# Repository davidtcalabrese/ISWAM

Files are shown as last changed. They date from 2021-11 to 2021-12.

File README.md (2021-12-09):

# ISWAM
## IoT Severe Weather Alert Monitor ⛈️ 🚨 🌪️ 🚨 🌊

ISWAM's purpose is to inform users in real time about current weather conditions as well as any possible alerts. It consists of a full stack node  application that accesses and processes NWS alerts and live weather data, and then broadcasts it to the browser  as well as on an IoT device I'm calling "The Puck". The Puck is an ESP32 microcontroller with integrated  WiFi attached to a small LCD screen and a ring of colorful LEDs. It's enclosed in a 3d-printed plastic case that resembles a hockey puck. 

The front end receives a zip code from the user, sends it to a node application for processing, receives the response and displays it to the page. The node application receives the parameters from the user, and consumes various REST APIs to collect data on current weather conditions as well as any potential safety alerts. It then processes and formats the data, sending the results back to the front end as well as to The Puck which exposes its own API.   
 
### APIs used
* [National Weather Service API ](https://www.weather.gov/documentation/services-web-api)
  * alert from UGC endpoint: /alerts/active/zone/{zoneId}
  * UGC from coordinates endpoint: https://api.weather.gov/points/{lat},{long}
  * Coordinates from UGC endpoint (for testing): https://api.weather.gov/zones/forecast/{UGC}
* [Weatherbit.io API](https://www.weatherbit.io/api)
  * weather from zipcode endpoint: https://api.weatherbit.io/v2.0/current/&postal_code={zip}&country=US
* [Zippopatmus](https://www.zippopotam.us/)
  * Geographic coordinates from zipcode endpoint: http://api.zippopotam.us/us/${zip} 
  * Alert from zip codehttps://api.weatherbit.io/v2.0/alerts?country=US&postal_code={zip}
* [Google Maps Geocoding API](https://developers.google.com/maps/documentation/geocoding/start)
  * Used the reverse geocoding API for testing purposes, zip code from coordinates: https://maps.googleapis.com/maps/api/geocode/json?latlng={lat},{long}

### Flowchart
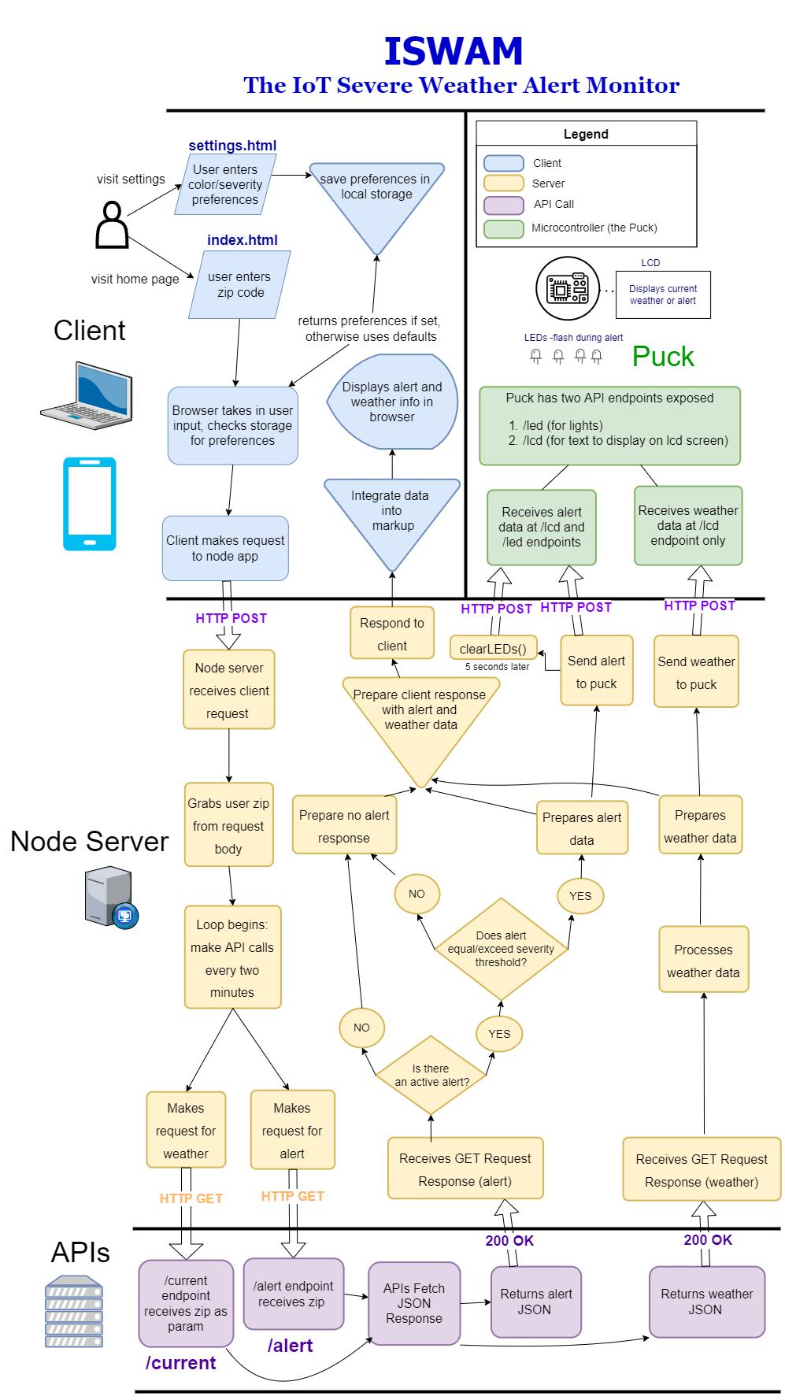
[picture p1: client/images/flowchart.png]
ISWAM Flowchart


### Images
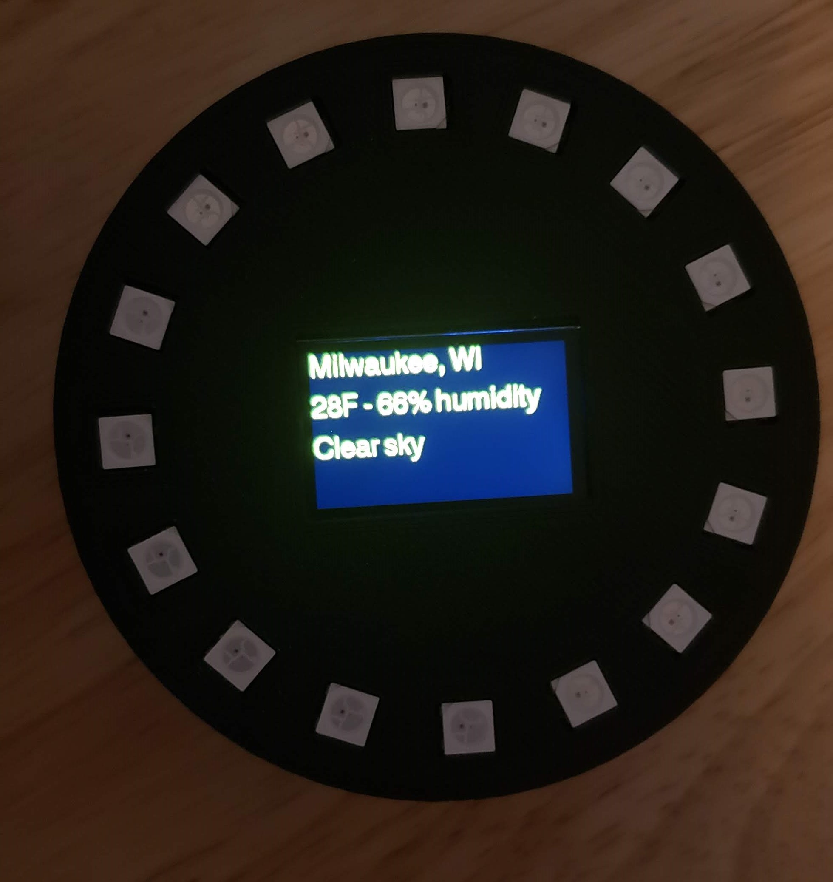
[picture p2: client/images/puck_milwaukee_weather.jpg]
Puck Weather Display

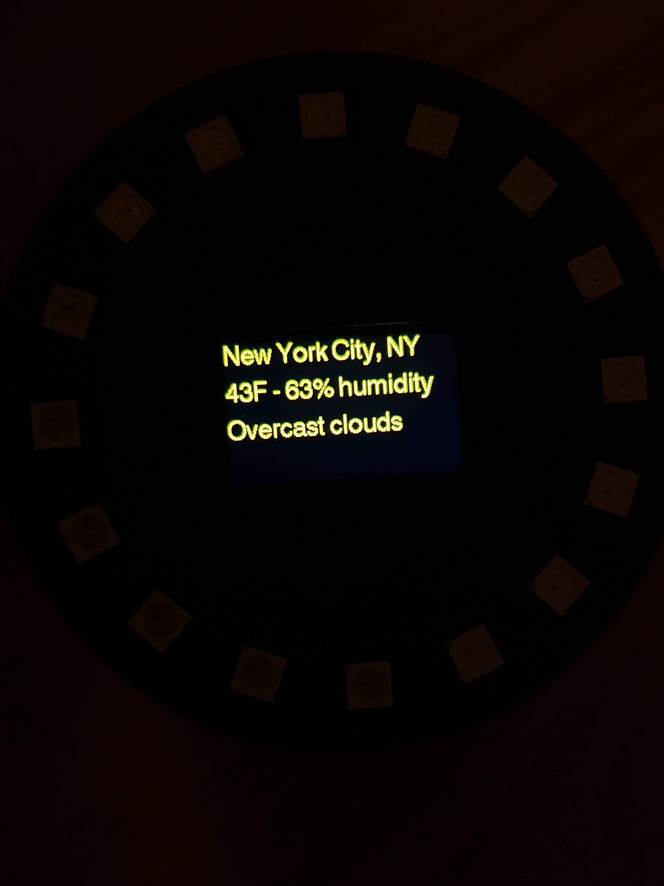
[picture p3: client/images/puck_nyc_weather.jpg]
Puck Weather Display

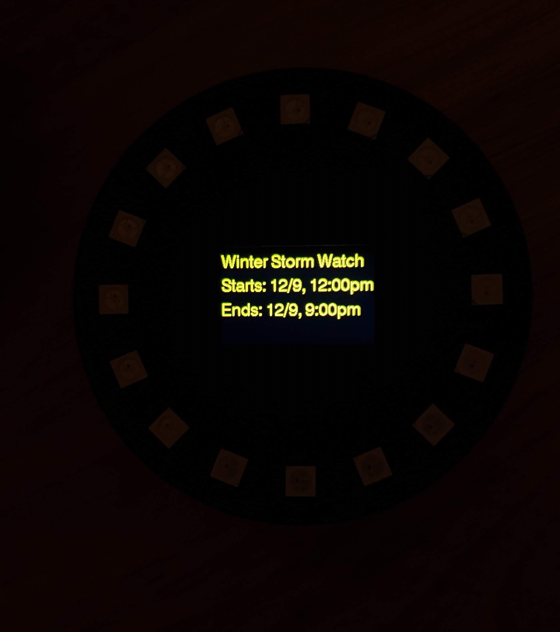
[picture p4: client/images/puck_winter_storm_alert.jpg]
Puck Alert Display

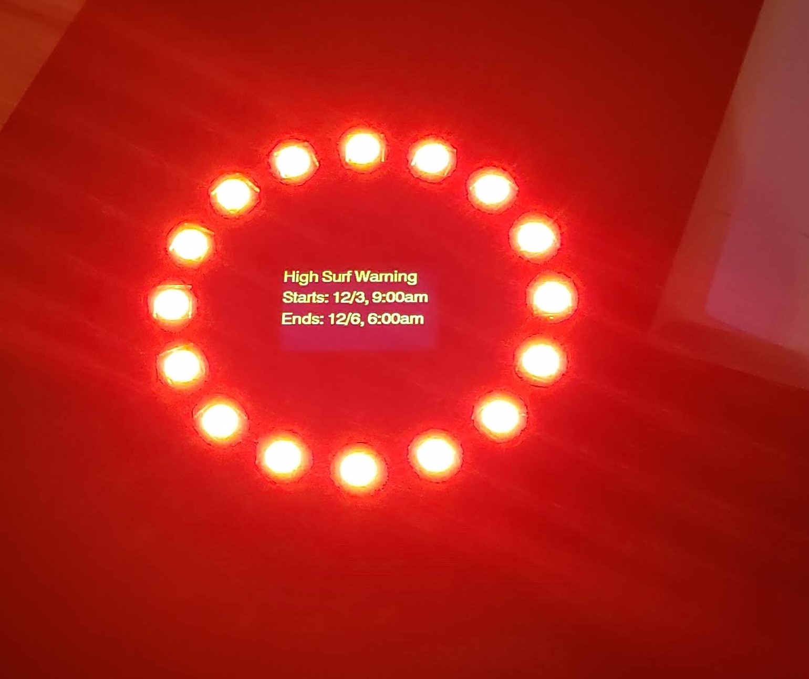
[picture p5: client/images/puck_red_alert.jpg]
Puck Alert Red

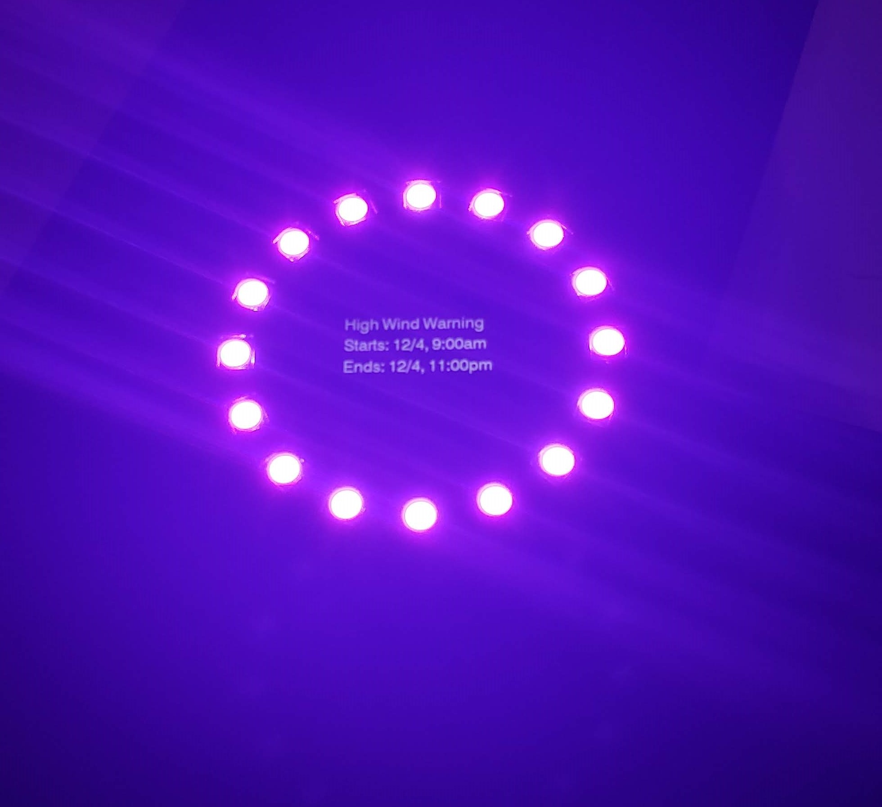
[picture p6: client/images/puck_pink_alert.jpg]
Puck Pink Pink

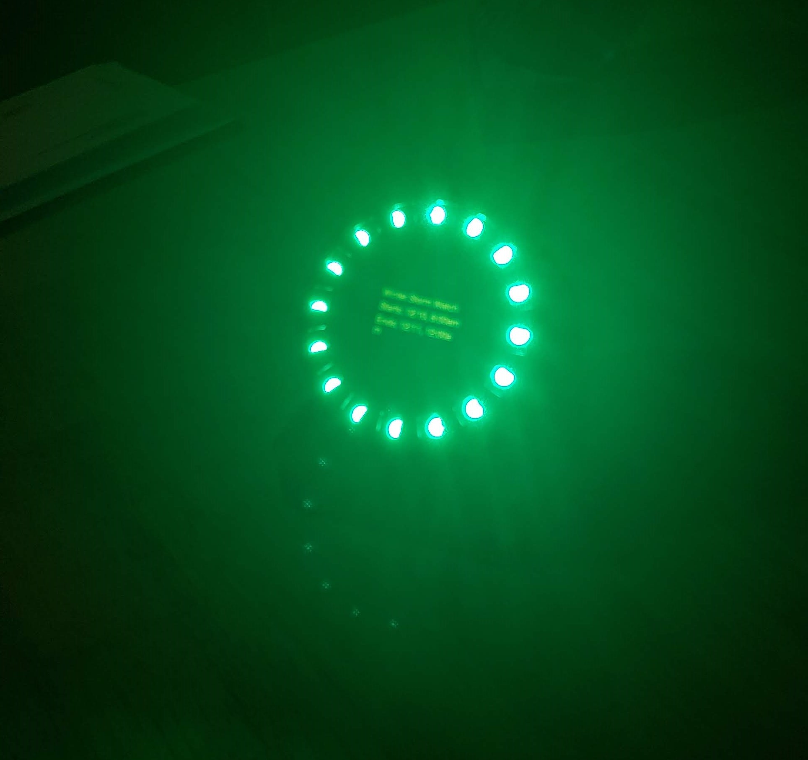
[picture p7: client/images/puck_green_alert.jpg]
Puck Pink Green


### Hardware
[Link to Embedded Code README](/embedded/SW/README.md)

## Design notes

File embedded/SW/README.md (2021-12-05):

# ISWAM Puck Embedded Hardware and Software

## Introduction

ISWAM system consists of a cloud based server component, a user interface which runs in a local web browser, and an embedded display
deivce called the Puck. This document describes the Puck's design and construction.

The Puck needed to be small, battery powered (at least for short periods of time), connect to the Internet via WiFi, display data
to a user and most importantly be very fast to prototype. The entire Puck conception through final version construction happend in 
less than 10 days of evening work.

Many software and hardware components were chosen to reduce time risk of the project. This included starting with a processor and
software ecosystem with mature WiFi and networking support as well as availability of inexpensive and small development boards
that included the processor, display, battery and USB functions.

The ESP32 processor from Espressif fit the bill and so was chosen for the processor. Existing example code that illustrated similar
functionality to what was needed for ISWAM was used as a starting point. A compact develompent board was bought on Amazon for rapid
shipment, as well as a ring of addressable LEDs, battery and other components.

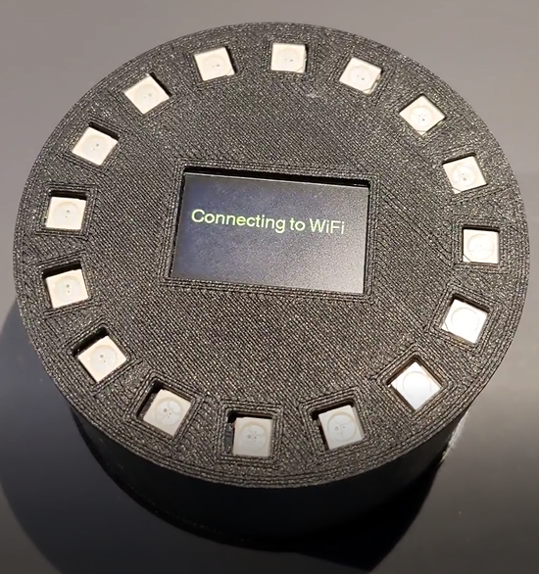
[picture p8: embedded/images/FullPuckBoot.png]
Fully assembled Puck


## Block Diagram

The Puck consists of the TTGO board (continaing ESP32 processor, Flash, battery charger chip and battery connector, IPS 1.14 inch
display and USB C connector for charging, programming ande debug), a ring of 16 WS2812 LEDs, BME280 digital pressure/temperature/humidity
sensor, small LiPo battery pack, on/off switch, DC-DC power supply and level shifter.

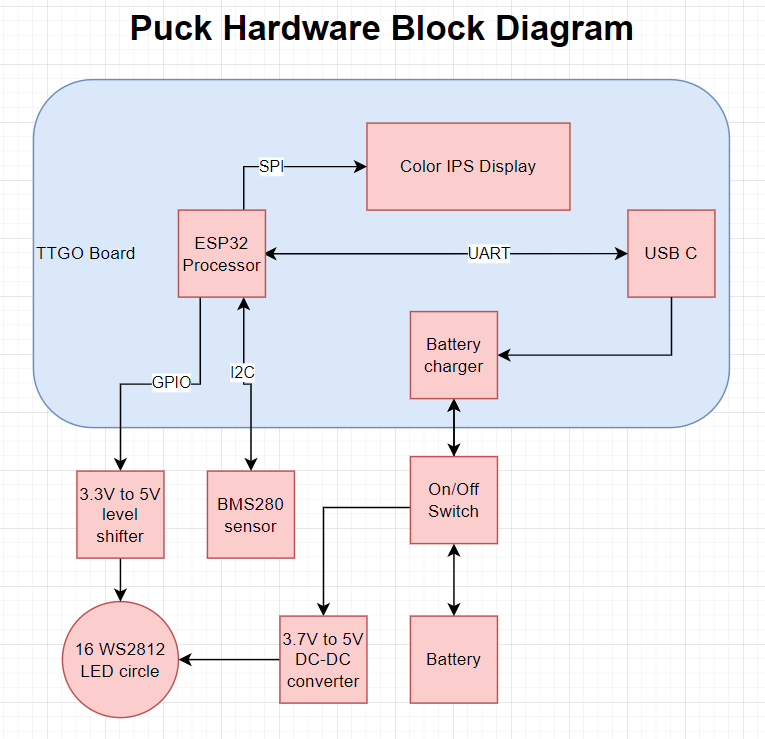
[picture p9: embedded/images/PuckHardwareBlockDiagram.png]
Hardware Block Diagram of Puck


The DC-DC boost board is required because the WS2812 LEDs need 5V, and when under battery power 5V pin from the TTGO board only supplies
about 3.7V (from the battery). So the battery voltage is run through the boost converter before powering the LEDs so they will always get
5V no matter if the Puck is on USB or battery power.

The on/off switch is a latch-on/latch-off type, and it breaks the connection with the battery. This means that the battery can only charge
if the on/off switch is turned on and the USB connector is getting 5V.

The USB connection on the TTGO board is utilized for powering the system, providing battery charging power, and serial communications
with the PC (for programming and serial I/O while running as a debug output).

## Schematic

Schematic of Puck electronics

Before the Puck mechanicals were worked out, a breadboard was used for software development and electrical circuit checkout.

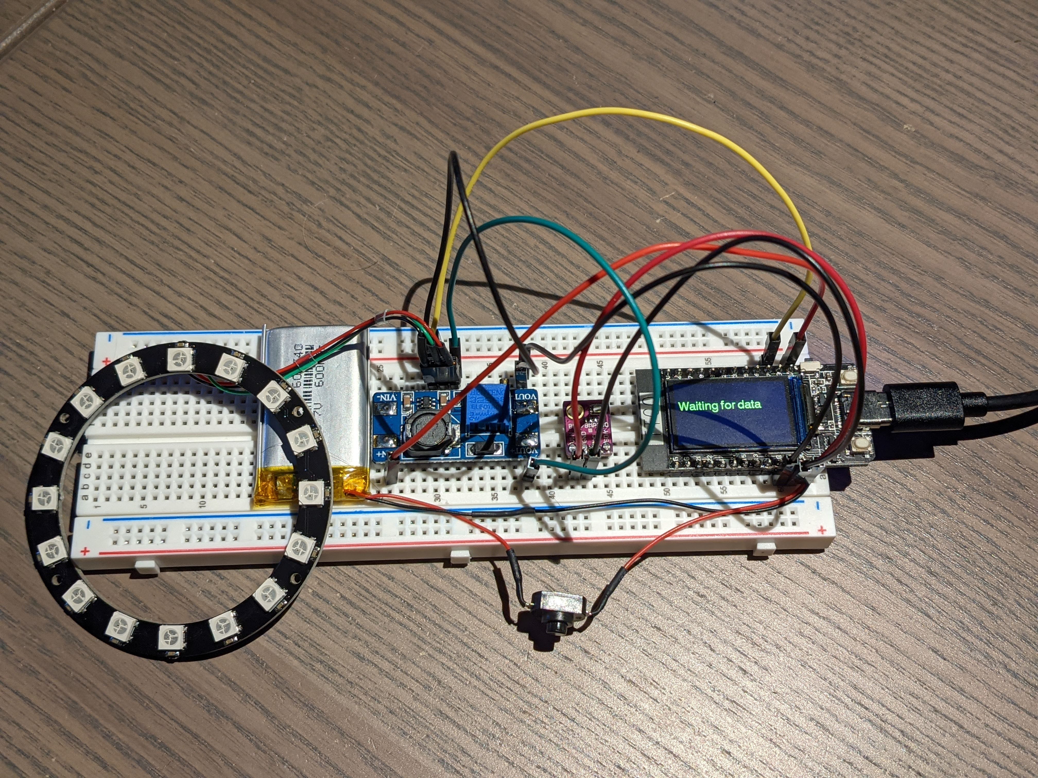
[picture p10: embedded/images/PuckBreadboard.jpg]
Fully assembled Puck


## Mecanical Construction

All of the electronics in the Puck were soldered to a protoboard using point to point wiring. 

All Puck electrical components:
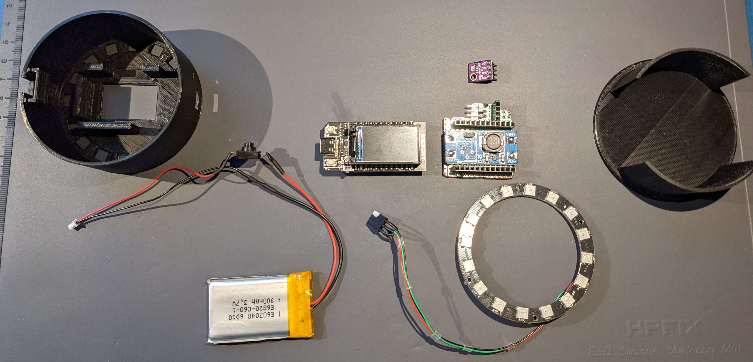
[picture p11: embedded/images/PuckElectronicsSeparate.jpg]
Top view of Puck electronics


Bottom view of just the protoboard, with level shifter and point to point wiring visible:
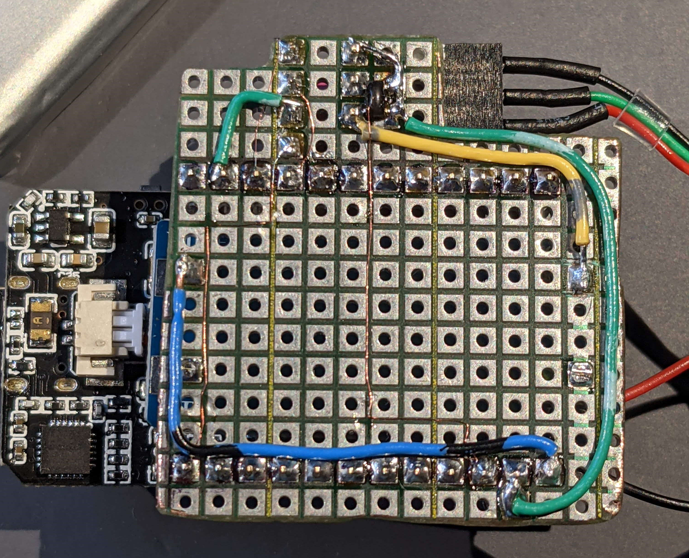
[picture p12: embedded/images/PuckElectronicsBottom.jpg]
Bottom view of Puck electronics


The stack of components then sit down inside a 3D printed housing. 
The housing consists of two parts - a top and bottom piece. The IPS screen was separated from the TTGO and a 3D printed spacer was
added between it and the board. This allows the display pannel to sit almost flush with the top of the Puck, increasing readability.

The TTGO board and the sensor board are both mounted on headers with sockets in the protoboard so that they can be replaced with identical
units if they ever develop faults.

The thre lines to the LED ring us a small 0.1" header and socket so that the the LEDs can be disconnected from the protoboard for ease of
disassembly.

## Software

PlatformIO is used a an extension within Visual Studio Code to compile and download new images to the Puck. Several libraries (listed below) 
are used for standard ESP32 WiFi, networking, JSON parsing, sensor communication and display communication. The default ESP32 FreeRTOS is used
by the libraries to manage system resources.

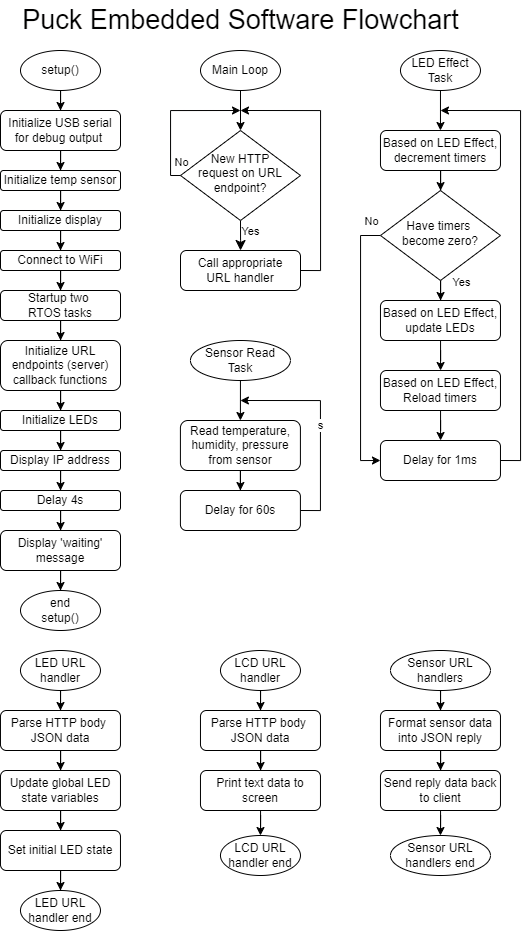
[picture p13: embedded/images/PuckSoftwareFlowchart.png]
Puck embedded software flowchart


Using the Webserver library, the Puck code presents sevarl URL endpoints on its webserver interface for any client to connect to as it's API.
The endpoints that display information on the LEDs or screen (/led, /lcd, /icon) are used with HTTP POST requests, where simple JSON data
is sent in the body of the request. The Puck software parses the JSON data and applies it to the LEDs or display.

The other endpoints (/temperature, /humidity, /pressure, /env) all report back sensor data if an HTTP GET request is made to them.

During system initalization, two RTOS tasks are started up - one for reading the sensor every 60 seconds, and the other for managing the 
LED state (primarily for the implementation of flashing). Also during system intialization the URL endpoints are added to the webserver
configuration.

The main loop() function simply waits for HTTP GET or POST requests on the defined API endpoints. When one is seen, the appropriate callback
function is called and the data processed appropraitely.

The various icon images are stored as arrays in header files and included at the top of the main.cpp file. The API provides a mechanism for 
selecting one of these icons and displaying it anywhere on the screen.

## How to build

### Software

* Install Visual Studio Code

* Install Git for Windows

* From within VSC, install the Platform IO extension. It takes a while, and will require a restart of VSC. Also allow the standard C/C++ extension pack to install.

* From the Platfrom IO Home window, select Open Project, then navigate to ISWAM/embedded/SW and choose that directory

* On left hand side of VSC, click on Platform IO (alien head). Then from Project Tasks window, select General->Build. 

* This should build all of the pieces of the project, and you should get a "Success" in the terminal window.

* To download the newly build image to the Puck, plug the Puck into the PC usign a USB C cable, then click the General->Upload task from the Project Tasks window. 
PlatformIO should be able to find the serial port that the Puck has created and upload the new image.

* To view the serial output from the Puck as it is running, connect a termainl emulator (like TeraTerm) to the serial port created by the Puck, and set it to 9600
baud. Be sure to disconnect from that serial port before attempting to upload to the Puck again.

### Hardware

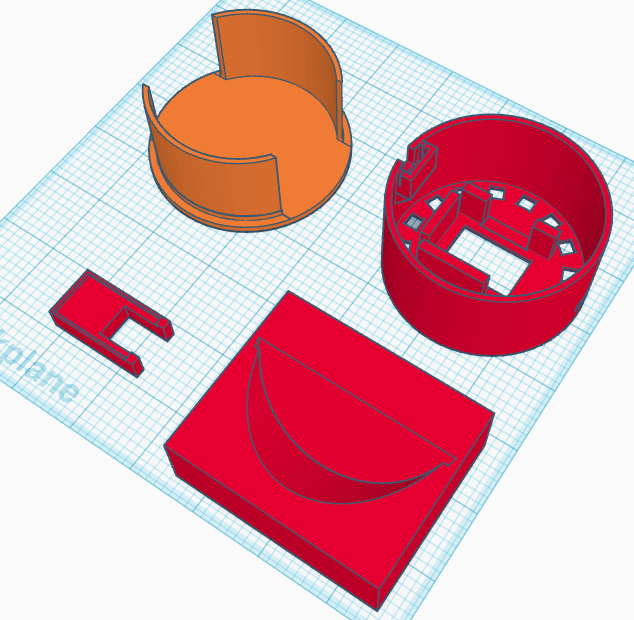
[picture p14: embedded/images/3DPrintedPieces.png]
3D Printable Parts for Puck


* In the embedded/HW directory are all of the .stl files for the four 3D printed pieces. Slice them with
your choice of slicer and print on a 3D printer.

* Assemble the hardware pieces acording to the above schematic and pictures.

* Modify the TTGO board by carefully removing the display from the board (no need to 
unsolder the display flex), clean off the adhesive, then use double sided sticky
tape to adhere the display to the spacer and the spacer to the board.

* Insert the LED ring into the top Puck shell.

* Insert the rest of the electronics into the top of the Puck shell.

* Insert the on/off switch into the cutout in the side of the top shell piece.

* Attach the battery to the bottom of the electronics stack with double sided
sticky tape and foam.

* Press the bottom shell of the Puck into the top shell. If the LED ring is
properly sitting in the top shell, the bottom shell will hold the ring
tight against the top face of the Puck. The bottom shell should be a press fit
into the top shell.

* The assembled Puck can be placed into the holder for easier readability.s

## Hardware Links

These are the primary components used to construct the Puck:

* GitHub repo for ESP32 + Display board:
https://github.com/Xinyuan-LilyGO/TTGO-T-Display

* Product page for EPS32 + Display board:
http://www.lilygo.cn/prod_view.aspx?TypeId=50033&Id=1126&FId=t3:50033:3

* Amazon link for ESP32 + Display board:
https://www.amazon.com/gp/product/B099MPFJ9M/ref=ppx_yo_dt_b_asin_title_o09_s01?ie=UTF8&psc=1

* Temp/Pressure/Humdity sensor:
https://www.amazon.com/gp/product/B07V5CL3L8/ref=ppx_yo_dt_b_asin_title_o08_s00?ie=UTF8&psc=1

* LED Ring (16 LED version)
https://www.amazon.com/gp/product/B08LMZZK2Z/ref=ppx_yo_dt_b_asin_title_o09_s00?ie=UTF8&psc=1

* DC-DC step up converter:
https://www.amazon.com/gp/product/B089JYBF25/ref=ppx_yo_dt_b_asin_title_o00_s01?ie=UTF8&psc=1

* Level Shifter:
https://www.digikey.com/en/products/detail/texas-instruments/SN74LV1T125DBVR/4555571

* Power switch:
https://www.amazon.com/gp/product/B086L2GPGX/ref=ppx_yo_dt_b_asin_title_o00_s01?ie=UTF8&psc=1

## Software Links

* The ESP32 code started from this example: [ESP32 Rest API Server](https://www.survivingwithandroid.com/esp32-rest-api-esp32-api-server/)

* Sensor library: https://github.com/adafruit/Adafruit_BME280_Library, https://github.com/adafruit/Adafruit_Sensor

* LED (WS2812) Library: https://github.com/adafruit/Adafruit_NeoPixel

* LCD library:
https://github.com/Bodmer/TFT_eSPI

* Weather graphics from: https://www.weatherbit.io/api/codes

* Using this image converter to get to C arrays: http://www.rinkydinkelectronics.com/_t_doimageconverter565.php

## Contact Information

If you have any questions about this project, please contact David Calabrese: dCalabrese414@gmail.com or Brian Schmalz: brain@schmalzhaus.com

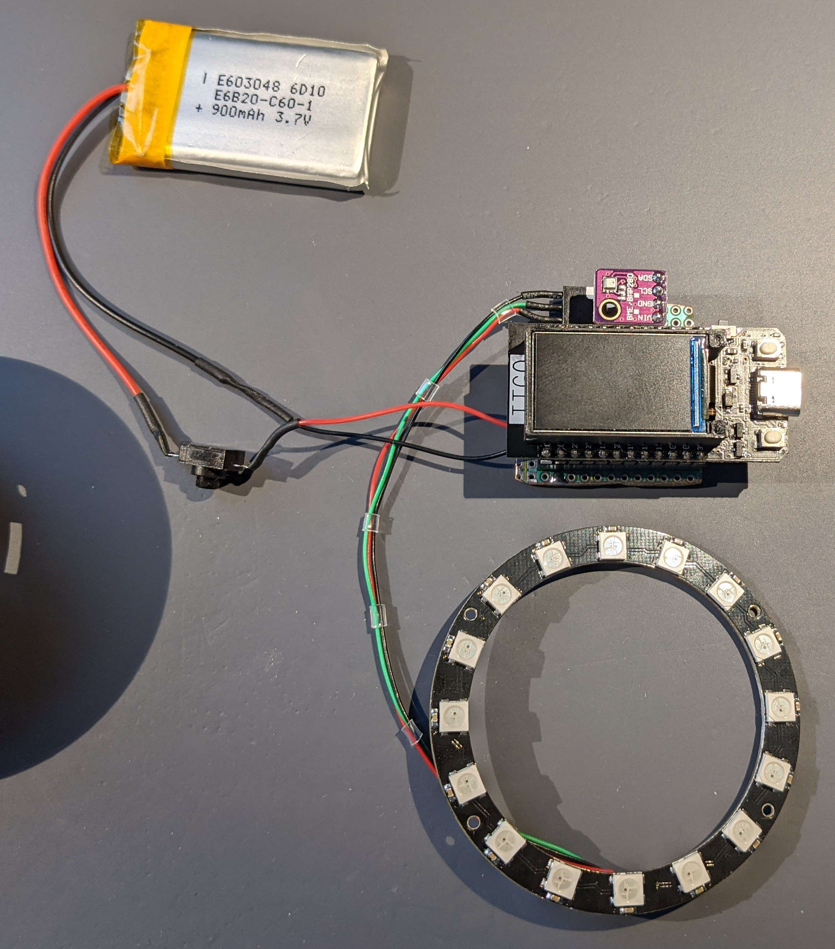
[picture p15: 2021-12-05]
embedded/images/PuckElectronicsTop.jpg

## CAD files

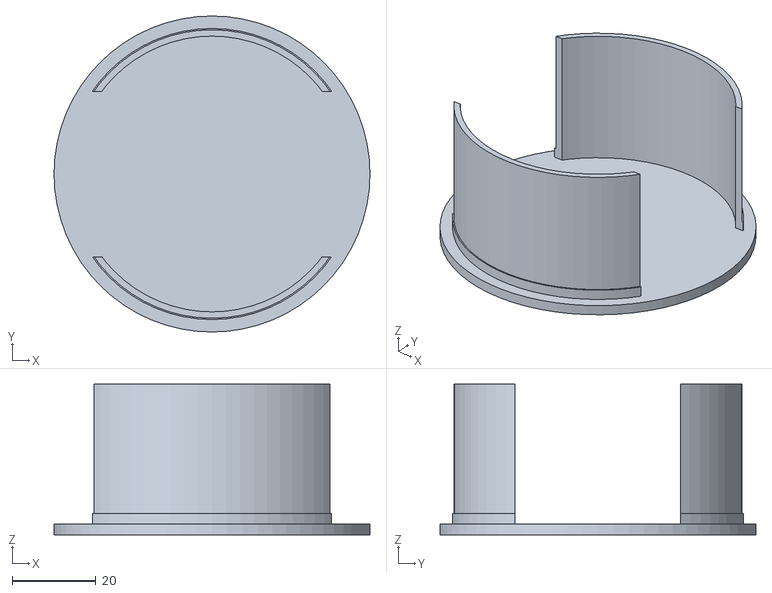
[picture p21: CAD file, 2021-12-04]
embedded/HW/ISWAM_Bottom_v1.stl
75.7 x 75.7 x 36.1

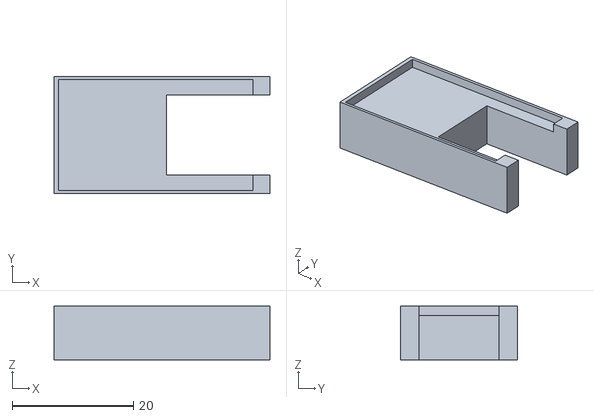
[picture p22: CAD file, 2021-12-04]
embedded/HW/ISWAM_Spacer_v1.stl
35.6 x 19.3 x 8.89

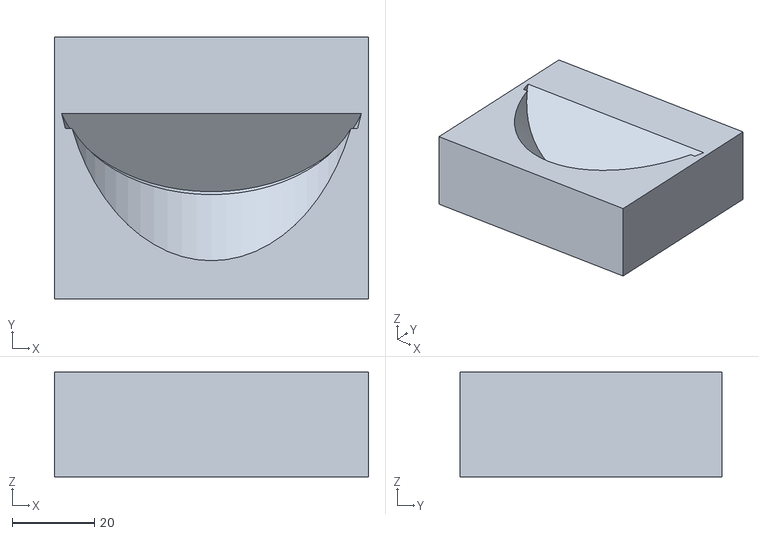
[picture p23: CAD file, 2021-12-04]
embedded/HW/ISWAM_Holder_v1.stl
76.2 x 63.5 x 25.4

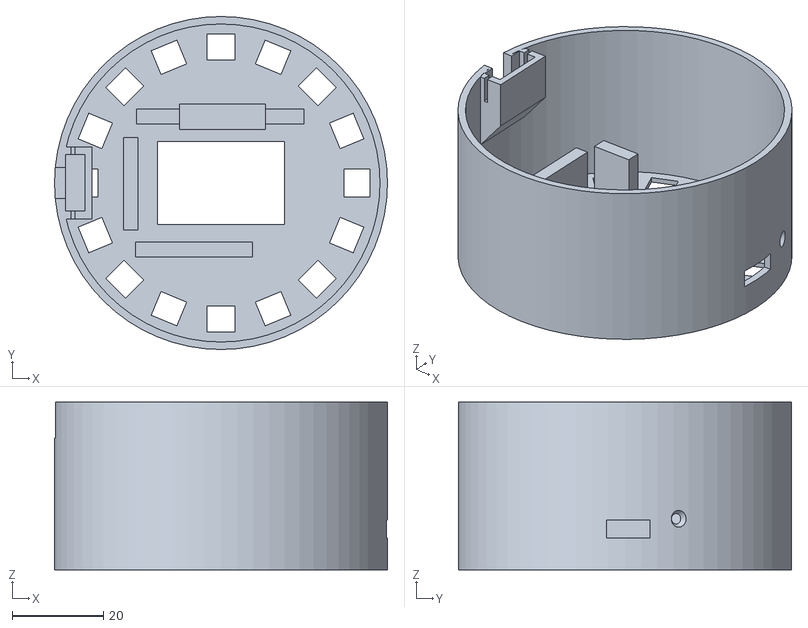
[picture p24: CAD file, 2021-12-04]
embedded/HW/ISWAM_Top_v1.stl
73.2 x 73.2 x 36.8

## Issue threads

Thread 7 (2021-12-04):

Prevent embedded code from wrapping over long text strings on LCD to next 'line'

EmbeddedMan, 2021-12-04:
Currently when the embedded code gets a string to display on the LCD which is longer than can fit, it will wrap the extra characters down to the next line. This is undesirable. Instead, the code should compute the width of the supplied string, and 'chop off' any extra that doesn't fit on one line.

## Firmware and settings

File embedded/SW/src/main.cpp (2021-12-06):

/**
  ******************************************************************************
  * @file    main.cpp
  * @author  Brian Schmalz
  * @brief   Top level source code file for ISWAM Puck embedded code
  * 
  * See https://github.com/davidtcalabrese/ISWAM for full information
  *
  ******************************************************************************
  * @attention
  * 
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
  ******************************************************************************
  */ 

/* Includes ------------------------------------------------------------------*/

#include <Arduino.h>
#include <WiFi.h>
#include <FreeRTOS.h>

#include "sensor.h"
#include "handlers.h"
#include "led.h"
#include "lcd.h"

/* Private typedef -----------------------------------------------------------*/

/* Private define ------------------------------------------------------------*/

/* Private macro -------------------------------------------------------------*/

/* Private variables ---------------------------------------------------------*/

// Credentials for the access point we want to connect to
/// TODO: Reeaaallly not ideal to store credentials in plan text in Github repo.
/// Switch this to a more secure method
const char *SSID = "casa calabrese";
const char *PWD = "calabre4";

/* Public variables ----------------------------------------------------------*/

/* Private function prototypes -----------------------------------------------*/


/* Private functions ---------------------------------------------------------*/

/**
  * @brief Connects to WiFi access point. Keeps trying forever.
  * @note  
  * @param none
  * @retval none
  */
void connectToWiFi(void) 
{
  Serial.print("Connecting to ");
  Serial.println(SSID);
  
  WiFi.begin(SSID, PWD);
  
  while (WiFi.status() != WL_CONNECTED) 
  {
    Serial.print(".");
    delay(500); 
  }
 
  Serial.print("Connected. IP: ");
  Serial.println(WiFi.localIP());
}
 
/* Public functions ---------------------------------------------------------*/

/**
  * @brief Arduino setup() function. Called once by Arduino core at boot
  * @note  
  * @param none
  * @retval none
  */
void setup(void) 
{
  // Initialize all the things.
  Serial.begin(9600);
  sensor_Init();
  lcd_Init();
  connectToWiFi();
  handlers_Init();
  // Display the IP address that DHCP gave to us on the LCD display for 4 seconds
  /// TODO: Add version string printout to IP display screen
  lcd_DisplayIP();
  delay(4000);
  // Print a 'waiting for data' message until something is sent to us
  lcd_DisplayWaiting();
}
 
/**
  * @brief Arduino loop() function. Called repeatedly by Arduino core during running
  * @note  
  * @param none
  * @retval none
  */
 void loop(void) 
{
  handlers_Run();
}

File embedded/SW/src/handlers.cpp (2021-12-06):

/**
  ******************************************************************************
  * @file    handlers.cpp
  * @author  Brian Schmalz
  * @brief   Webserver hanlder callback functions
  * 
  * See https://github.com/davidtcalabrese/ISWAM for full information
  *
  ******************************************************************************
  * @attention
  * 
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
  ******************************************************************************
  */ 

/* Includes ------------------------------------------------------------------*/
#include <Arduino.h>
#include <WiFi.h>
#include <FreeRTOS.h>
#include <ArduinoJson.h>
#include <WebServer.h>
#include "sensor.hpp"
#include "led.h"
#include "lcd.h"

/* Private typedef -----------------------------------------------------------*/

/* Private define ------------------------------------------------------------*/

/* Private macro -------------------------------------------------------------*/

/* Private variables ---------------------------------------------------------*/

// Web server running on port 80
WebServer server(80);

// JSON data buffer
StaticJsonDocument<500> jsonDocument;
char buffer[500];

/* Public variables ----------------------------------------------------------*/

/* Private function prototypes -----------------------------------------------*/

/* Private functions ---------------------------------------------------------*/

/**
  * @brief  Creates JSON data in buffer from one piece ofsensor data
  * @param  tag : string name for tag element
  * @param  value : numerical value element
  * @param  unit : string name for units element
  * @retval none
  */
void create_json(char *tag, float value, char *unit) 
{ 
  jsonDocument.clear(); 
  jsonDocument["type"] = tag;
  jsonDocument["value"] = value;
  jsonDocument["unit"] = unit;
  serializeJson(jsonDocument, buffer);
  Serial.println("Buffer:");
  Serial.println(buffer);  
}
 
/**
  * @brief  Add one new sensor value into existing JSON document
  * @param  tag : string name for tag element
  * @param  value : numerical value element
  * @param  unit : string name for units element
  * @retval none
  */
void add_json_object(char *tag, float value, char *unit) 
{
  JsonObject obj = jsonDocument.createNestedObject();
  obj["type"] = tag;
  obj["value"] = value;
  obj["unit"] = unit; 
}

/**
  * @brief  Called when /temperature endpoint is accessed. Return temp JSON
  * @param  none
  * @retval none
  */
void getTemperature(void) 
{
  char tag[] = "temperature";
  char unit[] = "°C";
  Serial.println("Get temperature");
  create_json(tag, sensor_GetTemperature(), unit);
  server.send(200, "application/json", buffer);
}
 
/**
  * @brief  Called when /humidity endpoint is accessed. Return humidity JSON
  * @param  none
  * @retval none
  */
void getHumidity(void) 
{
  char tag[] = "humidity";
  char unit[] = "%";
  Serial.println("Get humidity");
  create_json(tag, sensor_GetHumidity(), unit);
  server.send(200, "application/json", buffer);
}
 
/**
  * @brief  Called whne /pressure endpoint is accessed. Return pressure JSON
  * @param  none
  * @retval none
  */
void getPressure(void) 
{
  char tag[] = "pressure";
  char unit[] = "mBar";
  Serial.println("Get pressure");
  create_json(tag, sensor_GetPressure(), unit);
  server.send(200, "application/json", buffer);
}
 
/**
  * @brief  Called when /env endpoint is accessed. Return all three values in JSON response
  * @param  none
  * @retval none
  */
void getEnv(void) 
{
  char tag1[] = "temperature";
  char tag2[] = "humidity";
  char tag3[] = "pressure";
  char unit1[] = "°C";
  char unit2[] = "%";
  char unit3[] = "mBar";
  Serial.println("Get env");
  jsonDocument.clear();
  add_json_object(tag1, sensor_GetTemperature(), unit1);
  add_json_object(tag2, sensor_GetHumidity(), unit2);
  add_json_object(tag3, sensor_GetPressure(), unit3);
  serializeJson(jsonDocument, buffer);
  server.send(200, "application/json", buffer);
}

/**
  * @brief  Called when JSON data is sent to /post endpoint. Parse JSON and update LED state
  * @param  none
  * @retval none
  */
void handlePostLED(void) 
{
  if (server.hasArg("plain") == false) 
  {
    //handle error here
    return;
  }

  String body = server.arg("plain");
  Serial.println(body);
  deserializeJson(jsonDocument, body);
  
  // Get RGB components
  int red = jsonDocument["red"];
  int green = jsonDocument["green"];
  int blue = jsonDocument["blue"];
  int effect = jsonDocument["blink"];
  int onTime = jsonDocument["onTime"];
  int offTime = jsonDocument["offTime"];

  Serial.println("LED Packet:");
  Serial.print("Red: ");
  Serial.print(red);
  Serial.print(" Green: ");
  Serial.print(green);
  Serial.print(" Blue: ");
  Serial.print(blue);
  Serial.print(" Effect: ");
  Serial.print(effect);
  Serial.print(" onTime: ");
  Serial.print(onTime);
  Serial.print(" offTime: ");
  Serial.println(offTime);

  led_changeEffect(red, green, blue, effect, onTime, offTime);

  // Respond to the client
  server.send(200, "application/json", "{}");
}

/**
  * @brief  Called when data POSTed to /lcd endpoint. Parse JSON and update screen with text.
  * @param  none
  * @retval none
  */
void handlePostLCD(void) 
{
  if (server.hasArg("plain") == false) 
  {
    //handle error here
    return;
  }

  String body = server.arg("plain");
  Serial.println(body);
  deserializeJson(jsonDocument, body);
  
  // Get RGB components
  const char* text1 = jsonDocument["text1"];
  const char* text2 = jsonDocument["text2"];
  const char* text3 = jsonDocument["text3"];
  const char* text4 = jsonDocument["text4"];

  Serial.println("LCD Text Packet:");
  Serial.print("text1: ");
  Serial.println(text1);
  Serial.print("text2: ");
  Serial.println(text2);
  Serial.print("text3: ");
  Serial.println(text3);
  Serial.print("text4: ");
  Serial.println(text4);

  // Actually print the lines of text out on the LCD
  lcd_printTextLines(text1, text2, text3, text4);

  // Respond to the client
  server.send(200, "application/json", "{}");
}

/**
  * @brief  Called when data POSTed to /icon endpoint. Parse JSON and draw icon on screen
  * @param  none
  * @retval none
  */
void handlePostIcon(void) 
{
  if (server.hasArg("plain") == false) 
  {
    //handle error here
    return;
  }

  String body = server.arg("plain");
  Serial.println(body);
  deserializeJson(jsonDocument, body);
  
  // Get RGB components
  const char* iconName = jsonDocument["icon"];
  int xCoord = jsonDocument["x"];
  int yCoord = jsonDocument["y"];
 
  /// TODO: Actually draw the icon 
  // Use iconName, x and y coordinates to draw a grpahic on the screen
//  tft.pushImage(1, 60, 64, 64, a02d_smoke_64);

  // Respond to the client
  server.send(200, "application/json", "{}");
}

/* Public functions ---------------------------------------------------------*/
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

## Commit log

2021-11-25 Comitting ESP32 files
2021-11-26 fix for case sensitivity match
2021-11-27 switches to one space between methods
2021-11-27 adds LED color option to settings
2021-11-27 switches light input id
2021-11-27 removes obj props
2021-11-27 removes props
2021-11-27 adds text file of sample alert data
2021-11-28 adds flowchart draft
2021-11-29 Fixed board/LCD selection problem with updated LCD library the "right" way (in Platformio.ini)
2021-11-30 Got basic endpoints defined. LED and LCD appear to be working well. "Icon" still needs to be finished.
2021-12-01 adds current working version (ISWAM_3)
2021-12-03 alert LEDs working
2021-12-04 Added raw images of Puck assembly, started embedded readme.md
2021-12-05 adds flowchart to images
2021-12-05 updates README, adds flowchart
2021-12-05 new flowchart
2021-12-05 WIP: Puck Schematic
2021-12-05 adjust white color to not overload circuit
2021-12-05 Added Embedded schematic
2021-12-05 Added first version of embdded SW flowchart to readme
2021-12-07 adds new tiered flowchart
2021-12-07 lowers rgb values for alert default
    sending out alerts at 255, 255, 255 for white seemed to overload the leds and not all of them would light. I am adjusting white color to 211x3, which is still a nice white color
2021-12-07 adds interval radio buttons
2021-12-07 fixes radio button ids
2021-12-08 narrows flowchart for easier viewing
2021-12-08 fixes flowchart typo
2021-12-09 adds console logs to track progress

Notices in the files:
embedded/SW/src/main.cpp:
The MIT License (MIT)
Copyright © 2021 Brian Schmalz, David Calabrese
